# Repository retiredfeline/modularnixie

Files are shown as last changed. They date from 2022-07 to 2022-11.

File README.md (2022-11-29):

# Modular nixie board

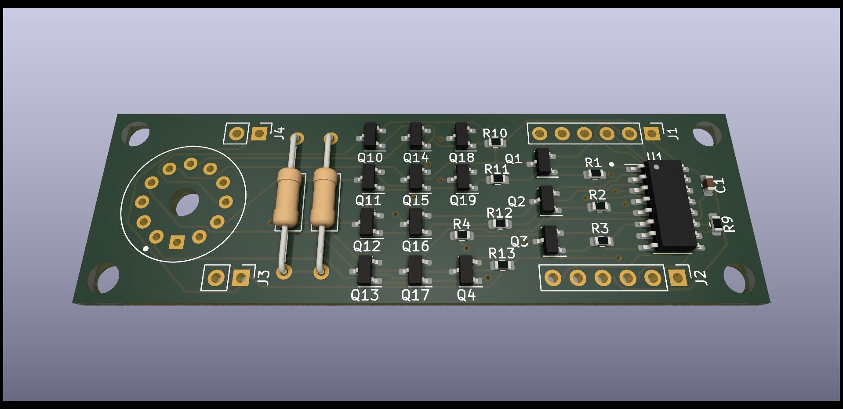
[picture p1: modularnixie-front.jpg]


These are the Kicad design files for the [Modular nixie project at Hackaday](https://hackaday.io/project/188427-modularnixie).

## Versioning

First release November 2022

## Notes

The minimum lines required to use this board are: GND, SER (data), SRCLK (shift), RCLK (strobe) and power for the shift register 74HC595 and the nixie. The shift register lines are designed to cascade for multiple digits. The hardware configuration calls for the least significant digit to be shifted in first.

## Authors

* **Ken Yap**

## License

See the [LICENSE](LICENSE.md) file for license rights and limitations (MIT).

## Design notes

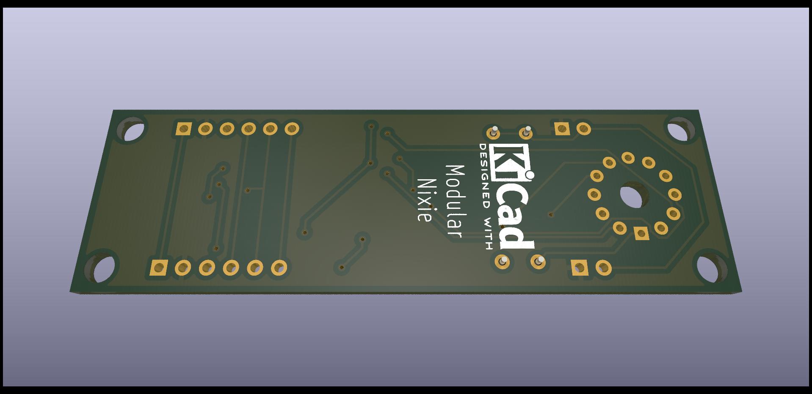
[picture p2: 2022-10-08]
modularnixie-back.jpg

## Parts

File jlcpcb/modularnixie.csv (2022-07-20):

Comment | Designator | Footprint | LCSC
100n | C1 | Capacitor_SMD:C_0603_1608Metric | C14663
MMBT5551 | Q1,Q2,Q3,Q4,Q10,Q11,Q12,Q13,Q14,Q15,Q16,Q17,Q18,Q19 | Package_TO_SOT_SMD:SOT-23 | C2145
22k | R1,R2,R3,R4,R9,R10,R11,R12,R13 | Resistor_SMD:R_0603_1608Metric | C31850

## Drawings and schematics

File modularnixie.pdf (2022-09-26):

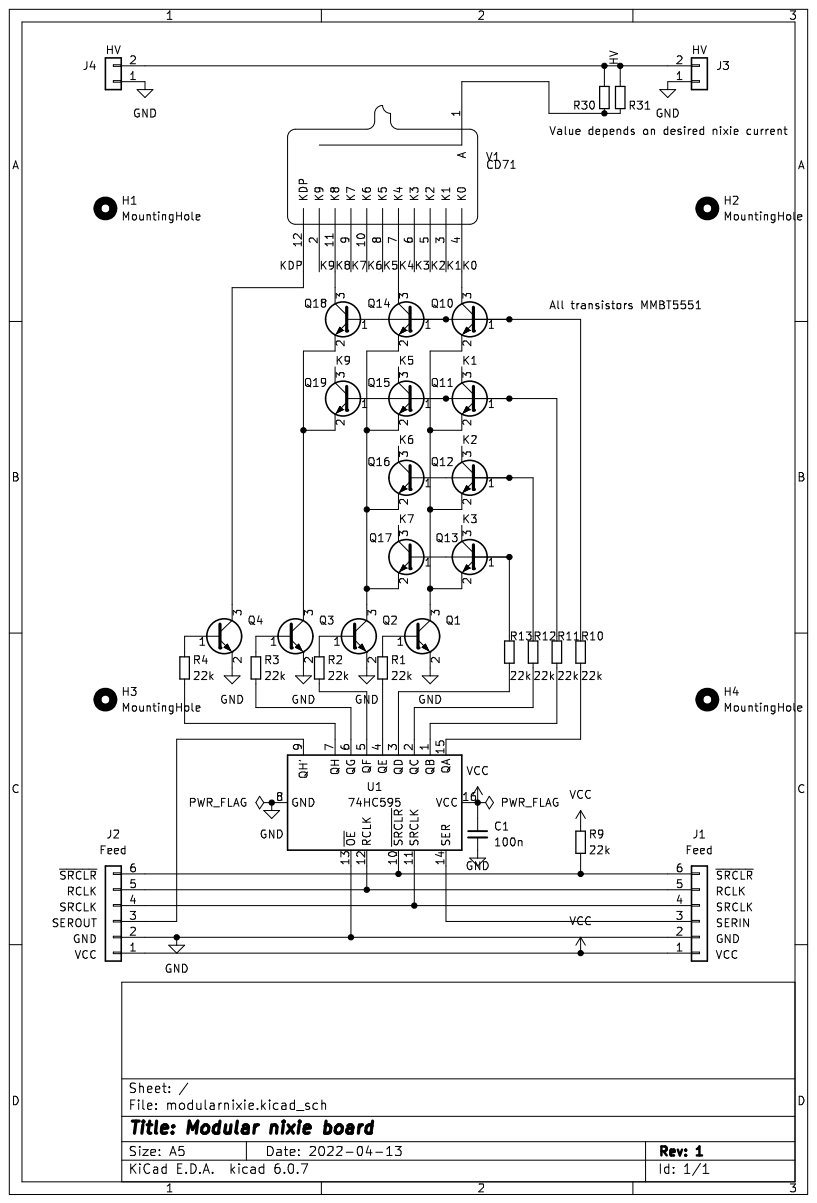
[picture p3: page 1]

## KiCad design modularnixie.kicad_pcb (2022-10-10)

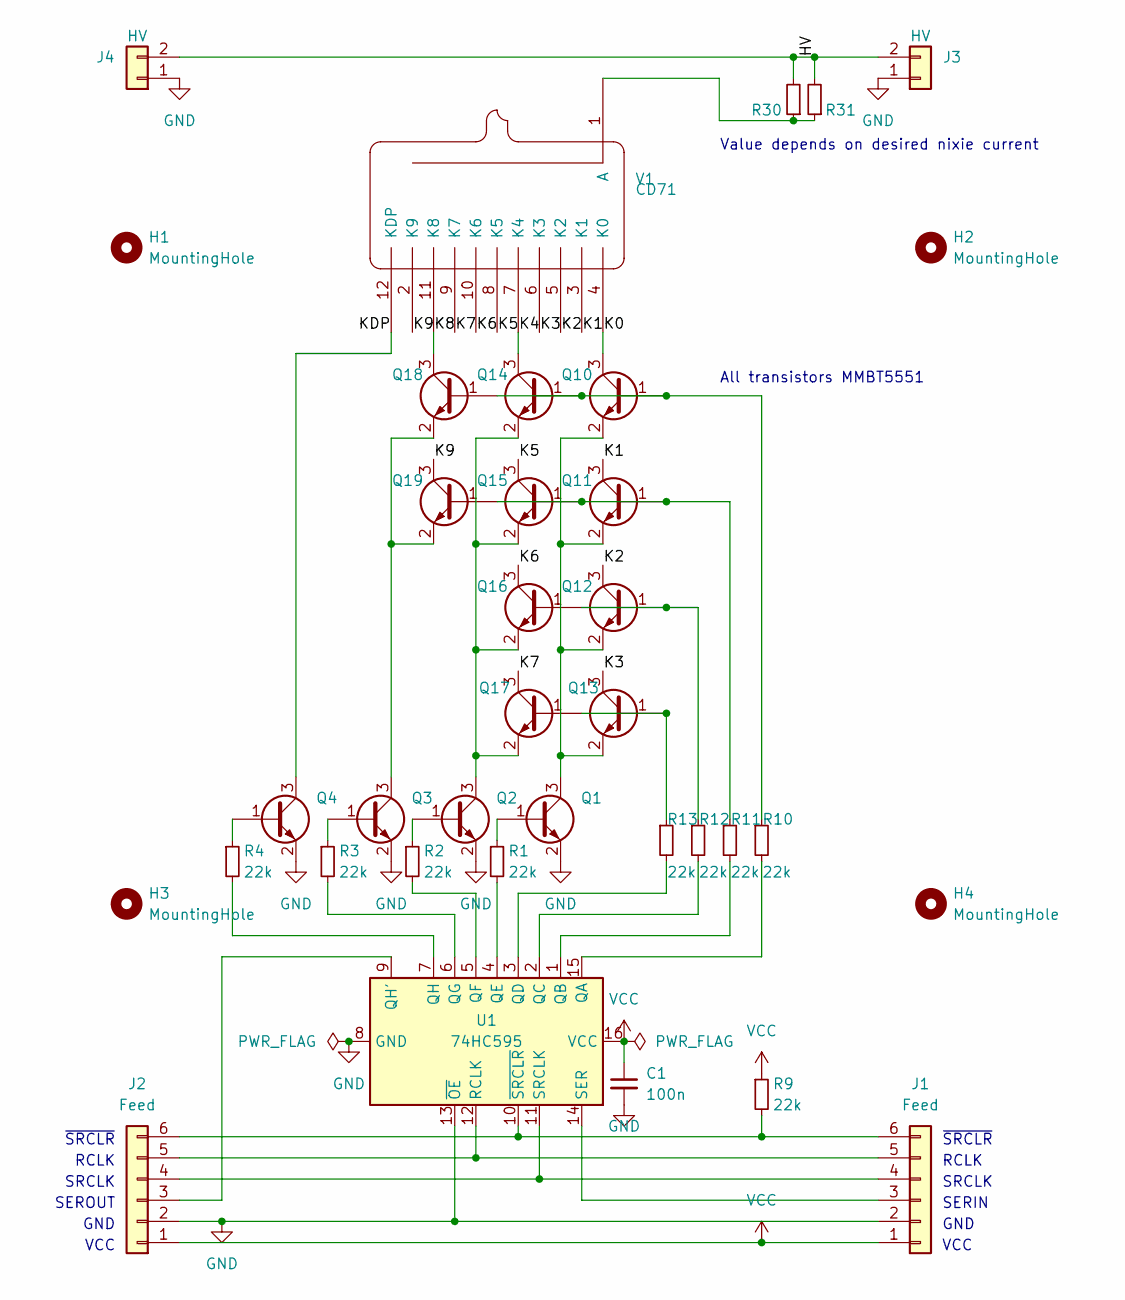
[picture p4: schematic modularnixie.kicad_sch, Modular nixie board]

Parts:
C1: 100n; C_0603_1608Metric; LCSC C14663
H1, H2, H3, H4: MountingHole; MountingHole_3.2mm_M3
J1, J2: Feed; PinHeader_1x06_P2.54mm_Vertical
J3, J4: HV; PinHeader_1x02_P2.54mm_Vertical
Q1, Q2, Q3, Q4, Q10, Q11, Q12, Q13, Q14, Q15, Q16, Q17, Q18, Q19: MMBT5551; SOT-23; LCSC C2145
R1, R2, R3, R4, R9, R10, R11, R12, R13: 22k; R_0603_1608Metric; LCSC C31850
R30, R31: R_Axial_DIN0207_L6.3mm_D2.5mm_P15.24mm_Horizontal
U1: 74HC595; SOIC-16_3.9x9.9mm_P1.27mm; LCSC C5947
V1: CD71

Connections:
/HV: J3.2, J4.2, R30.2, R31.2
/K0: Q10.3 (C), V1.4 (K0)
/K1: Q11.3 (C), V1.3 (K1)
/K2: Q12.3 (C), V1.5 (K2)
/K3: Q13.3 (C), V1.6 (K3)
/K4: Q14.3 (C), V1.7 (K4)
/K5: Q15.3 (C), V1.8 (K5)
/K6: Q16.3 (C), V1.10 (K6)
/K7: Q17.3 (C), V1.9 (K7)
/K8: Q18.3 (C), V1.11 (K8)
/K9: Q19.3 (C), V1.2 (K9)
/KDP: Q4.3 (C), V1.12 (KDP)
GND: C1.2, J1.2, J2.2, J3.1, J4.1, Q1.2 (E), Q2.2 (E), Q3.2 (E), Q4.2 (E), U1.8 (GND), U1.13 (~OE)
unnamed: J1.3, U1.14 (SER)
unnamed: J1.4, J2.4, U1.11 (SRCLK)
unnamed: J1.5, J2.5, U1.12 (RCLK)
unnamed: J1.6, J2.6, R9.2, U1.10 (~SRCLR)
unnamed: J2.3, U1.9 (QH')
unnamed: Q1.1 (B), R1.1
unnamed: Q1.3 (C), Q10.2 (E), Q11.2 (E), Q12.2 (E), Q13.2 (E)
unnamed: Q2.1 (B), R2.1
unnamed: Q3.1 (B), R3.1
unnamed: Q4.1 (B), R4.1
unnamed: Q10.1 (B), Q14.1 (B), Q18.1 (B), R10.1
unnamed: Q11.1 (B), Q15.1 (B), Q19.1 (B), R11.1
unnamed: Q12.1 (B), Q16.1 (B), R12.1
unnamed: Q13.1 (B), Q17.1 (B), R13.1
unnamed: Q2.3 (C), Q14.2 (E), Q15.2 (E), Q16.2 (E), Q17.2 (E)
unnamed: Q3.3 (C), Q18.2 (E), Q19.2 (E)
unnamed: R1.2, U1.4 (QE)
unnamed: R2.2, U1.5 (QF)
unnamed: R3.2, U1.6 (QG)
unnamed: R4.2, U1.7 (QH)
unnamed: R10.2, U1.15 (QA)
unnamed: R11.2, U1.1 (QB)
unnamed: R12.2, U1.2 (QC)
unnamed: R13.2, U1.3 (QD)
unnamed: R30.1, R31.1, V1.1 (A)
VCC: C1.1, J1.1, J2.1, R9.1, U1.16 (VCC)

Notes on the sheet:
RCLK
GND
SRCLK
VCC
SERIN
All transistors MMBT5551
Value depends on desired nixie current
SEROUT
~{SRCLR}

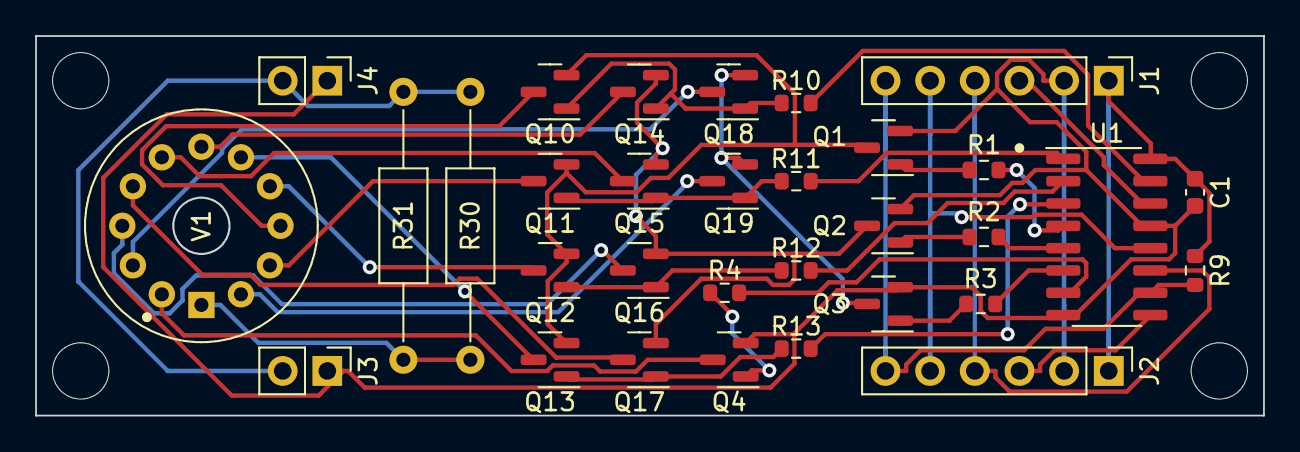
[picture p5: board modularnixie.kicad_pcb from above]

Board: 2 copper layers, 69.8 x 21.6 mm, 36 parts (0 on the bottom side), 39 nets.

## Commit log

2022-07-20 First release
    [modularnixie-B_Cu.gbr, modularnixie-B_Mask.gbr, modularnixie-B_Silkscreen.gbr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]
2022-07-20 Hide pinheaders for 3D rendering as normally wire links will be used
    [modularnixie.kicad_pcb]
2022-09-26 Stray wire, transistor type typo
    [modularnixie.kicad_sch]
2022-10-10 Actually replace SOP-16 with SOIC-16 to get 3D model
    [modularnixie.kicad_pcb, modularnixie.kicad_sch]
2022-12-20 Tidy placement of mounting hole symbol
    [modularnixie.kicad_sch]
2023-01-08 Add datasheet
    [modularnixie.kicad_sch]
